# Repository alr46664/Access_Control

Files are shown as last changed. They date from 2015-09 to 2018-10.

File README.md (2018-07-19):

# Table of Contents

- [Table of Contents](#table-of-contents)
- [Project](#project)
- [Pin Details and Project Requirements](#pin-details-and-project-requirements)
- [Pin Connection and Prototype Schematic](#pin-connection-and-prototype-schematic)
- [RFID Reader Operation](#rfid-reader-operation)
- [IR Reader Operation](#ir-reader-operation)
- [Change RFID Master Code](#change-rfid-master-code)
- [More Details](#more-details)

# Project

Build an RFID control system that can register and unregister cards individually using either the RFID reader, or the IR receiver.

# Pin Details and Project Requirements

- Pin 2 (int0) => DATA0 of RFID Reader (Wiegand 34 bits protocol)
- Pin 3 (int1) => DATA1 of RFID Reader (Wiegand 34 bits protocol)
- Requires ATMEGA328 or ATMEGA328p Arduino to work

# Pin Connection and Prototype Schematic
See the [Fritizing Schematic](Fritzing/RFID.fzz) for the Arduino pin connection layout.

# RFID Reader Operation
- Pass Master Tag 1 time and wait to access door
- Pass it 2 times to register the next non-master card
- Pass it 3 times to unregister the next non-master card

# IR Reader Operation
- Buttons 0-9 are numerical buttons and are parsed to unsigned long once confirmed. 
- Buttons Two-Arrow-Left-Right and U/SD are OK and Cancel buttons respectively. So they confirm or cancel the operation/code.

# Change RFID Master Code

 1. In the normal operation mode (do not pass master rfid card in the rfid reader not even once), using the IR, press MODE btn.
 2. Enter the actual MASTER RFID TAG and press OK.
 3. If incorrect, buzzer will fire. If the code was correct, then type in the new MASTER RFID and press OK.
 4. If operation succeeded, LED will flash.

# More Details
See the [manual/main.pdf](manual/main.pdf) (written in Portuguese) for more details about the operation of the system.

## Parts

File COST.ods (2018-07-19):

Itens | Qtd | Custo (Unit) | TOTAL
Cartao RFID EM4100 125kHz | 2 | R$ 4,80 | R$ 9,60
Cabo Ethernet Cat5 | 4 | R$ 1,00 | R$ 4,00
Borne 2 Terminais | 3 | R$ 2,00 | R$ 6,00
Conector Energia Circular | 1 | R$ 2,00 | R$ 2,00
Conector Ethernet Macho | 1 | R$ 0,30 | R$ 0,30
Conector Ethernet Femea | 1 | R$ 5,00 | R$ 5,00
Leitor RFID EM4100 125kHz | 1 | R$ 37,70 | R$ 37,70
Arduino + Shield + IR + Relay | 1 | R$ 50,00 | R$ 50,00
Fonte 12VAC 1A HDL | 1 | R$ 50,00 | R$ 50,00
Fonte 12VDC 1A | 1 | R$ 20,00 | R$ 20,00
Caixas de Protecao | 2 | R$ 15,00 | R$ 30,00
TOTAL |  |  | R$ 214,60
LUCRO |  | 30,00% | R$ 64,38
PRECO FINAL |  |  | R$ 278,98

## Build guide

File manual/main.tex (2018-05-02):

\documentclass[a4paper, 12pt]{article}

\usepackage[portuges]{babel}
\usepackage[utf8]{inputenc}
\usepackage{amsmath}
\usepackage{indentfirst}
\usepackage{graphicx}
\usepackage[colorinlistoftodos]{todonotes}

\title{Sistema RFID}

%author{Caio Rosa \\ João Antônio do Amarante \\ Rodrigo \\ Thuane}

%\date{\today}

\usepackage{float}
\usepackage{listings}
\usepackage{subcaption} 

% space between footnote-footnote
\setlength{\footnotesep}{0.6cm}

% space between text-footnote
\setlength{\skip\footins}{1cm}

\begin{document}
%\maketitle

\begin{titlepage}
	\begin{center}
%     \begin{figure}[H]
%     \centering
%     \includegraphics[width=7cm]{LOGO}
%     \end{figure}

% 		\huge{Instituto Federal de Educação, Ciência e Tecnologia de São Paulo}

\vspace{10pt}
        
        \vspace{85pt}
        
		\textbf{\LARGE{Sistema de Controle de Acesso}}\\
		\large{Tecnologia RFID 125 kHz com (Des)Cadastramento Seletivo}
		\vspace{8cm}
		
	\end{center}
	
	\begin{flushleft}
		\begin{tabbing}
			Autores:\qquad\= André Madureira\\
			\>Luiz Madureira\\
%             \> Nome do Aluno 3 - 17202122\\
% 			Professor\> Nome do Professor \\
% 			Horário\> Qua - 15:00-17:00\\
		
	\end{tabbing}		  
	\end{flushleft}
	
	\begin{center}
		\vspace{\fill}
		Salvador, 05 de Maio de 2017
	\end{center}
\end{titlepage}
%%%%%%%%%%%%%%%%%%%%%%%%%%%%%%%%%%%%%%%%%%%%%%%%%%%%%%%%%%%
\newpage
\tableofcontents
\thispagestyle{empty}

\newpage
\pagenumbering{arabic}

%%%%%%%%%%%%%%%%%%%%%%%%%%%%%%%%%%%%%%%%%%%%%%%%%%%%%%%%%
%%%%%%%%%%%%%%%%%%%%%%%%%%%%%%%%%%%%%%%%%%%%%%%%%%%%
\section{Acesso}

Passe a tag RFID no leitor do portão. Se a tag estiver cadastrada, o acesso será liberado. Caso contrário, um bip continuo será emitido pelo leitor.

\section{(Des)Cadastramento de Tags}

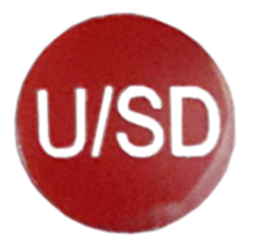
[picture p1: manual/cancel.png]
\newcommand{\alertaControleRemoto}{\textbf{\textit{*Caso você tenha digitado o código do cartão errado no Controle Remoto, pressione o botão \texttt{U/SD}  para cancelar e digite novamente o código desde o início.}}}

\newcommand{\avisoLuzVermelha}{Quando a luz vermelha for desligada, o sistema irá salvar as alterações e sair do modo de (des)cadastramento.}

\begin{enumerate}
\item Passe a tag mestre no leitor 1x para cadastrar cartões \textbf{OU} 2x para descadastrar (em ambos os casos a luz vermelha do leitor deverá se acender, sendo que no modo de descadastramento ela irá piscar antes de ficar acesa);
\item Passe o cartão a ser (des)cadastrado no leitor de cartões OU digite o código do cartão no Controle Remoto;
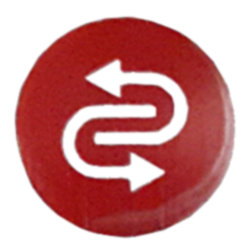
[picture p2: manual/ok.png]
\item Caso o controle remoto esteja sendo utilizado, pressione o botão \texttt{Seta Esquerda/Direita}  para confirmar o procedimento\footnote{\alertaControleRemoto};
\item Caso deseje (des)cadastrar mais cartões, retorne ao item 2 conforme a quantidade de cartões a serem (des)cadastrados (você tem até 20s para (des)cadastrar quantos cartões desejar);
\item Aguarde até que a luz vermelha se apague (demora cerca de 20s) \textbf{OU} passe o cartão mestre no leitor até que a luz vermelha se apague\footnote{\avisoLuzVermelha} (no modo de cadastramento basta passar uma vez, no modo de descadastramento será preciso passar 2x o cartão mestre).
\end{enumerate}

\newpage
\section{Alteração do Tag Mestre}

Em caso de extravio do tag mestre, será necessário cadastrar outro tag mestre no sistema. Ao fazer isso, o tag mestre anterior é automaticamente descadastrado. Para alterar o tag mestre siga os passos abaixo:

\begin{enumerate}
\item Pressione o botão \texttt{Mode} do Controle Remoto;
\item Digite o código do tag mestre atual\footnote{\label{controle_remoto_alerta}\alertaControleRemoto};
\item Pressione o botão \texttt{Seta Esquerda/Direita}  para confirmar;
\item Caso o código esteja errado um bip será emitido pelo leitor. Caso isso ocorra, retorne para o passo 1, do contrário prossiga para o passo abaixo;
\item Digite o código do novo cartão mestre\textsuperscript{\ref{controle_remoto_alerta}};
\item Pressione o botão \texttt{Seta Esquerda/Direita}  para confirmar;
\end{enumerate}

\textbf{Código do Tag Mestre Padrão:} 24121\\\par

\section{Controle Remoto}

    \begin{figure}[H]
    \centering
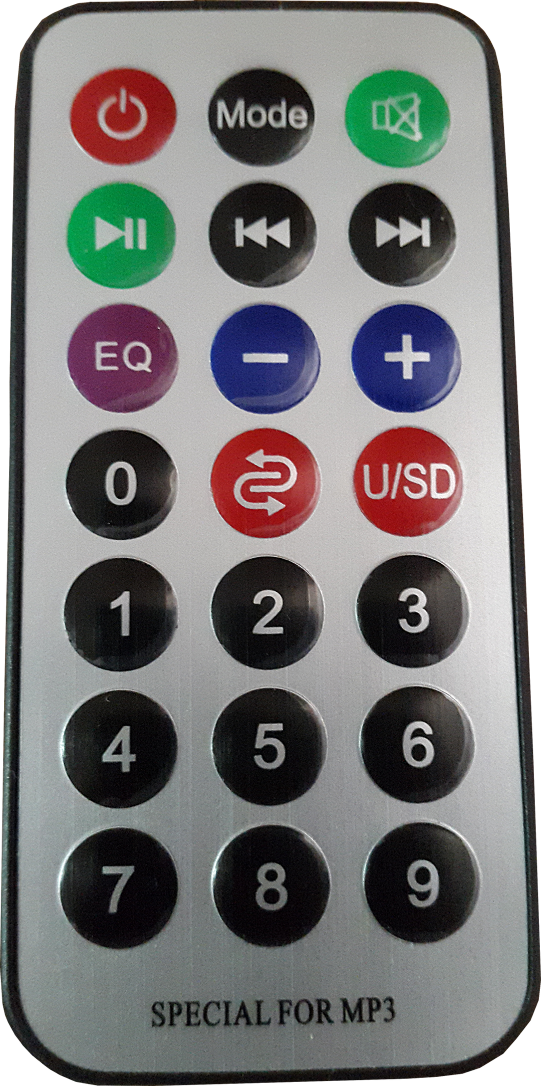
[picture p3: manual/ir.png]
    
    \end{figure}

% \newpage
% \section{Referências}

% [1] Chapman, S.J. -- Electric Machinery Fundamentals, 4th Edition;

% [2] Fitzgerald, A. E. -- Máquinas Elétricas, 2da Edição;

\end{document}

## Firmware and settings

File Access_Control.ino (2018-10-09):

/* 
 * Title:  RFID Door Access Control with MOSFET
 * Author: Andre Madureira
 * 
 * Default Master: 24121
 * 
 * Details:   
 * Using pin 2 (int0) and 3 (int1) as DATA0 and DATA1 
 * of Wiegand RFID Protocol. Supports both 26 bit and
 * 34 bit protocols (its better if we use the 36 bit 
 * protocol). Requires ATMEGA328 to work.
 * If RFID code is accepted, then activate control pin.
 * Otherwise, check for master code insertion.
 * 
 * RFID FUNCITONALITY:
 * Pass Master Tag 1 time and wait to access door
 * Pass it 2 times to register the next non-master card
 * Pass it 3 times to unregister the next non-master card
 * 
 * IR FUNCTIONALITY:
 * Buttons 0-9 are numerical buttons and are parsed to unsigned 
 * long once confirmed. 
 * Buttons Two-Arrow-Left-Right and U/SD are OK and Cancel buttons 
 * respectively. So they confirm or cancel the operation/code.
 * 
 * TO CHANGE MASTER RFID TAG:
 * 1. In the normal operation mode (do not pass master rfid not 
 *    even once), using the IR, press MODE btn.
 * 2. Enter the actual MASTER RFID TAG and press OK.
 * 3. If incorrect, buzzer will ring. If code was correct, then
 *    type in the new MASTER RFID and press OK.
 * 4. If operation succeded, LED will flash.
 *    
 */

#include "Arduino.h" 
#include <avr/wdt.h>   // Watchdog Library (needs optiboot bootloader to work well)
#include <Wiegand.h>   // Wiegand RFID Library 

#include <PowerMgr.h>  // PowerManager Library
#include "Project.h"      // project GLOBAL header
#include "IDManager.h"  // RFID Tag Manager - Read EEPROM - Write EEPROM
#include "State.h"     // System State Tracker
#include "Bluetooth.h"  // Bluetooth 4.0 Manager

IDManager manager;     // RFID EEPROM manager    
State stateManager(&manager);    // stateManager state tracker
Bluetooth bluetooth(&manager);   // bluetooth controller
WIEGAND rfid;            // WIEGAND protocol RFID reader

void setup() {  
  // disable unused modules to reduce power consumption
  PowerMgr::setupModules((~POWER_EN_ALL) || POWER_EN_TIMER0 || POWER_EN_TIMER1 || POWER_EN_TIMER2 || POWER_EN_USART);    
  // debug mode begin
  #ifdef DEBUG_MODE
  Serial.begin(9600);            // INITIALIZE SERIAL PC COMMUNICATION    
  #endif
  // initialize devices, IDManager and stateManager variables
  manager.begin();
  stateManager.begin();  
  bluetooth.begin(9600);
  rfid.begin();                             
  // initialize watchdog timer
  // wdt_reset();                // reset watchdog  
  wdt_enable(WDTO_8S);           // watchdog configured to 8s
  wdt_reset();                   // reset watchdog  
}

void loop() {      
  wdt_reset();    
  if (bluetooth.isConnected()){
    bluetooth.execute();
    wdt_reset();          
  } else if (rfid.available()){
    // state manager logic here 
    // (register, unregister or access)
    RFID_CODE code = rfid.getCode();    
    stateManager.execute(code);  
    #ifdef DEBUG_MODE
    Serial.println("RECV RFID");
    #endif
  }    
  #ifdef DEBUG_MODE    
  if (Serial.available()){
    delay(150);
    while(Serial.available()){
      Serial.read();
    }
    Serial.print(F("MASTER CARD - "));
    Serial.println(manager.getMasterCode());
    Serial.println();
    Serial.println(F("CARD LIST"));
    for (int i = 0; i < manager.getTotalCards(); i++) {
      Serial.println(manager.getCard(i));
    }    
  }
  #endif
}

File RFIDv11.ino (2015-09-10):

/* 
 * Title:  RFID Door Access Control with MOSFET
 * Author: Andre Madureira
 * 
 * Details:   
 * Using pin 2 (int0) and 3 (int1) as DATA0 and DATA1 
 * of Wiegand RFID Protocol. Supports both 26 bit and
 * 34 bit protocols. Requires ATMEGA328 to work.
 * If RFID code is accepted, then activate control pin.
 * Otherwise, check for master code insertion.
 * 
 * Pass Master Tag 1 time and wait to access door
 * Pass it 2 times to register the next non-master card read
 * Pass it 3 times to unregister the next non-master card
 *    
 */

#include <avr/wdt.h>  //Watchdog Library (needs optiboot bootloader to work well)
#include <IRremote.h> //IR Library
#include <Wiegand.h>  //Wiegand RFID Library
#include "TYPES.h"    //Custom Project Constants and Types

RFID_CODE allow_code[ALLOW_CODE_SIZE]; //ALLOWED NON-MASTER ID'S
unsigned char allow_code_len;          //# OF IDS ALLOWED (MAX VALUE IS ALLOW_CODE_SIZE)

MasterFunction num_master_fnc = ACCESS_NULL; //KEEP TRACK OF MASTER ID FUNCTION  

unsigned long prev_time;   //PREVIOUS TIME COUNTER
String IR_str;             //String to store IR received signals
unsigned long save_to_EEPROM;  //SET WHICH POSITIONS NEED TO BE UPDATED INTO EEPROM,
                               //0 means do not save to EEPROM

WIEGAND rfid;
IRrecv ir(PIN_IR_RECV);

void setup() {
  wdt_enable(WDTO_8S);           //watchdog configured to 8s
  wdt_reset();                   //reset watchdog
  initialize_pins();             //SETUP PINS TO INITIAL VALUES AND SIGNAL DIRECTIONS
  Serial.begin(9600);            //INITIALIZE SERIAL PC COMMUNICATION
  rfid.begin();                  //INITIALIZE WIEGAND SERIAL-PARALLEL COMMUNICATION
  ir.enableIRIn();               //START IR RECEIVER
  read_codes_EEPROM();           //READ ID'S FROM EEPROM  
  prev_time = 0;                 //INITIALIZE PREV_TIME
  save_to_EEPROM = 0;            //DO NOT SAVE CODES TO EEPROM
  Serial.println(F("RFID Door Access Control - READY"));
  print_n_acc_codes();           //PRINT # OF IDS REGISTERED
}

void loop() {  
  wdt_reset();                   //reset watchdog
  if (rfid.available())              //CHECK FOR RFID AVAILABILITY    
    execute_rfid_fnc(rfid.getCode());  
  wdt_reset();                   //reset watchdog
  check_master_access();    
  check_ir_s_modes();
  wdt_reset();                   //reset watchdog
  write_codes_EEPROM();   //check if any codes need writing
}

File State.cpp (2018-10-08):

#include "State.h"

// ------------
//   PUBLIC
// ------------

State::State(IDManager* manager): 
    state(ACCESS),    
    timer(ITV_EEPROM),
    manager(manager),
    led(PIN_LED, PIN_LED_INIT, PIN_LED_DELAY), 
    control(PIN_CONTROL, PIN_CONTROL_INIT, PIN_CONTROL_DELAY),
    bzr(PIN_BZR, PIN_BZR_INIT, PIN_BZR_DELAY) 
    { }

void State::begin(){
    // initialize pins IN-OUT
    control.begin();
    led.begin();
    bzr.begin();    
    // reset system state
    resetState();
}

void State::setMasterCodeChgMode(){
    changeState(MASTER_CHG);
}

// run code based on System state
void State::execute(const RFID_CODE& code){
    int result = 0;         
    // keep door closed at all times
    control.reset();
    wdt_reset();        
    if (code > 0){
      if (manager->getMasterCode() == code){
          // change to next state
          nextState();
      } else {
          // perform action
          switch(state){  
          case ACCESS:                 
              if (manager->find(code) != -1){            
                  // allow access
                  control.digitalPulse();
              } else {
                  #ifdef DEBUG_MODE
                  Serial.print("Unregistered ID - ");        
                  Serial.println(code);   
                  #endif
                  // we have an error
                  result = 1;
              }
              break;          
          case REGISTER:                  // REGISTER FUNCTION (PASS 1-TIME MASTER ID)
              timer.start();
              result = manager->registerID(code);
              break;          
          case UNREGISTER:                  // UNREGISTER FUNCTION (PASS 2-TIMES MASTER ID)
              timer.start();
              result = manager->unregisterID(code);
              break;  
          case MASTER_CHG:    
              // DO NOTHING - wait for master code validation (above)
              break;
          case MASTER_CONFIRM: 
              // we know the master code is validated 
              manager->setMasterCode(code);
              nextState();
              break;
          default:
              break;                        
          } 
      }   
      // we had a problem 
      if (result != 0){                  
          bzr.digitalPulse();
      } 
    }
    // timeout returns to reset state
    if (timer.hasTimeoutHappened()){                
        resetState();
    }
}

void State::blinkLED(unsigned char div){
    led.digitalPulse(div);
}

void State::bzrBeep(unsigned char div){
    bzr.digitalPulse(div);
}

// ------------
//   PRIVATE
// ------------

// return next state
void State::nextState(){
    switch(state) {
    case ACCESS:
        changeState(REGISTER);
        break;
    case REGISTER:    
        changeState(UNREGISTER);
        break;
    case UNREGISTER:
        changeState(ACCESS);
        break;
    case MASTER_CHG:        
        changeState(MASTER_CONFIRM);
        break;
    case MASTER_CONFIRM:    
        changeState(ACCESS);        
        break;
    default:
        changeState(ACCESS);
        break;
    }
}

// reset to initial state
void State::resetState(){
    changeState(ACCESS);
}

// change program state to new state
void State::changeState(StateSystem st){
    state = st;
    switch(state) {
    case ACCESS:
        wdt_reset();  
        timer.stop();  
        #ifdef DEBUG_MODE
        Serial.println(F("Access Mode"));
        #endif
        led.reset();        
        // save any pending data to eeprom
        saveDataEEPROM();
        break;
    case REGISTER:
        wdt_reset();
        timer.start();
        #ifdef DEBUG_MODE
        Serial.println(F("Registration Mode"));
        #endif        
        // LED OPPOSITE STATE OF INITIAL 
        led.setState(1-PIN_LED_INIT);
        break;
    case UNREGISTER:
        wdt_reset();  
        timer.start();      
        #ifdef DEBUG_MODE
        Serial.println(F("Unregistration Mode"));
        #endif
        // blink LED in OPOSITE STATE OF INITIAL
        led.setState(1-PIN_LED_INIT);
        led.digitalPulse();
        break;
    case MASTER_CHG:
        wdt_reset();
        timer.start();        
        #ifdef DEBUG_MODE
        Serial.println(F("Master Change"));
        #endif
        // LED OPPOSITE STATE OF INITIAL 
        led.setState(1-PIN_LED_INIT);
        break;
    case MASTER_CONFIRM:
        wdt_reset();     
        timer.start();   
        #ifdef DEBUG_MODE
        Serial.println(F("Master Change Confirm"));
        #endif
        // blink LED in OPOSITE STATE OF INITIAL
        led.setState(1-PIN_LED_INIT);
        led.digitalPulse();
        break;
    default:        
        break;
    }
}

// save data to eeprom if needed
void State::saveDataEEPROM(){
    if (manager->hasUnsavedData()){
        manager->write_EEPROM();
    }
}

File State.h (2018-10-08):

#ifndef _State_H
#define _State_H

#include "Arduino.h" 
#include <avr/wdt.h>    // Watchdog Library (needs optiboot bootloader to work well)

#include <Scheduler.h>  // Scheduler class
#include "Project.h"       // global PROJECT defines
#include "Pin.h"        // Output Digital Pins Class
#include "IDManager.h"  // RFID Tag Manager - Read EEPROM - Write EEPROM

// CONTROL PIN
#define PIN_CONTROL         6          // # OF DIGITAL PIN TO CONTROL
#define PIN_CONTROL_DELAY   350L       // KEEP HIGH OUTPUT IN PIN_CONTROL FOR # MS
#define PIN_CONTROL_INIT    HIGH       // define control initial state

// LED
#define PIN_LED             4          // OUTPUT LED
#define PIN_LED_DELAY       400L       // MS TO BLINK LED 
#define PIN_LED_INIT        LOW        // define led initial state
// LED END

// BZR
#define PIN_BZR             5          // OUTPUT BUZZER
#define PIN_BZR_DELAY       400L       // MS TO MANAGE FREQUENCY BZR
#define PIN_BZR_INIT        HIGH       // define BZR initial state

// INTERVAL(ms) TO WAIT FOR OTHER TAGS TO BE (UN)REGISTERED, THEN SAVE TO EEPROM
#define ITV_EEPROM          20000      

// DEFINE SYSTEM STATES
enum StateSystem {ACCESS = 0, REGISTER, UNREGISTER, MASTER_CHG, MASTER_CONFIRM};     

class State {
public:    
    State(IDManager* manager);
    
    void begin();    
    void setMasterCodeChgMode();
    void execute(const RFID_CODE& code);

    void blinkLED(unsigned char div = 1);
    void bzrBeep(unsigned char div = 1);
private:
    Pin control, led, bzr; // out pins
    IDManager* manager;     // RFID EEPROM manager        
    Scheduler timer;       // timer to perform async actions
    unsigned char state;   // store system state

    void nextState();      
    void resetState();    
    void changeState(StateSystem st);
    void saveDataEEPROM();
};

#endif  // _State_H 

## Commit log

2015-09-09 RFID - VERSION 11 IMPLEMENTED: -(UN)REGISTER MODE - REGISTER ID VIA RFID SENSOR -(UN)REGISTER MODE - REGISTER ID VIA REMOTE CONTROL -ACCESS MODE - REGISTERED IDS CAN CONTROL RELAY (MASTER ID HAS A TI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
    DETAILS:
    -ACCESS MODE (MASTER ID PASS = 0 OR 1)
    -REGISTER MODE (MASTER ID PASS = 2)
    -UNREGISTER MDOE (MASTER ID PASS = 3)
    BUG FIXES:
    -SMALL IR_STR RECEIVE BUG IF USER PASS A CARD IN RFID WITHOUT USING THE OK OR CANCEL REMOTE CONTROL BTN
    -TIMEOUT OF MASTER ID FOR ACCESS DOES NOT BLOCK THE uC (USE MILLIS)
    -DELAYPULSE BLOCKS UC (USE DELAY)
    -WATCHDOG ENABLED FOR 8 SEC (USE wdt_reset TO AVOID INCORRECT BEHAVIOUR)
    -EEPROM IS BEING USED TO READ / STORE RFIDS IN TH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
    [RFIDv11.ino]
2015-09-10 RFID CONTROL - VERSION 12
    ENHANCEMENTS:
    -MINIMIZE EEPROM WRITE BY SETTING A TIME INTERVAL TO ALLOW MORE THAN ONE (UN)REGISTRATIONS \
    PER TIME
    -SAVE ONLY THE BYTES THAT WERE CHANGED AND ONLY THE RFID TAGS NEEDED
    TODO:
    -IMPLEMENT RESET FUNCTION FOR MASTER CODE
    [RFIDv11.ino]
2015-09-26 Added power management functions to disable specific modules of ATMEGA
2017-12-01 final release
    [low_pass.xls]
2018-04-16 Frintizing mounting sketch
    [RFID.fzz]
2018-07-19 added costs and final prototype and readme
    [COST.ods]
2018-10-09 fixed some erros in the ble comm - \r and \n need to be send to terminate line
    [Access_Control.ino, Bluetooth.cpp]
